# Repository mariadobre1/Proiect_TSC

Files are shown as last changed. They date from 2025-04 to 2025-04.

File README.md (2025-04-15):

# OpenBook

## Prezentare generala

Proiectul a fost realizat în cadrul disciplinei Testarea Sistemelor de Calcul și are ca scop crearea unui model 3D detaliat pentru o tabletă E-Book Reader. Am realizat proiectarea atât la nivel de circuit, cât și la nivel de design al produsului, utilizând programul Fusion360 de la Autodesk.

## Block Diagram
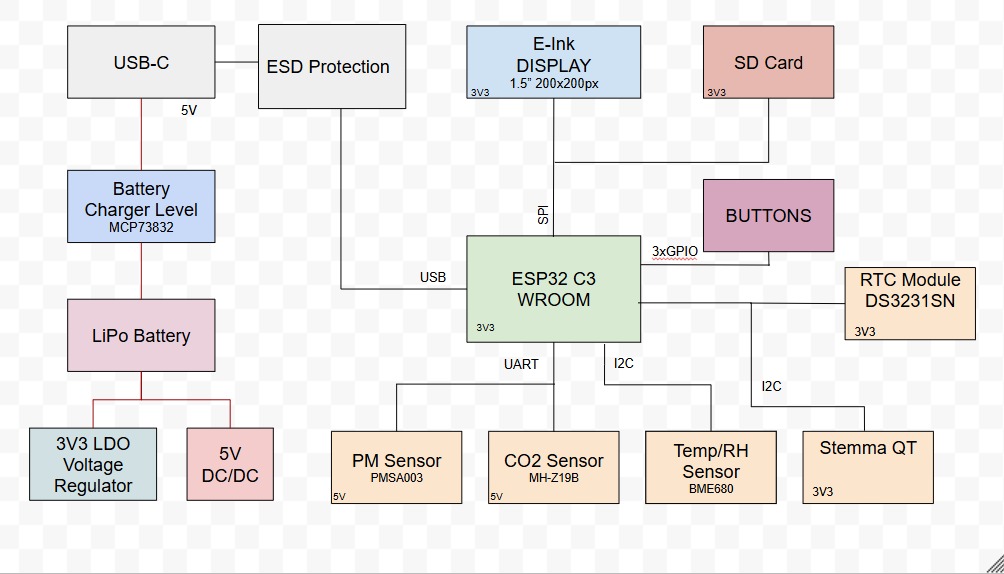
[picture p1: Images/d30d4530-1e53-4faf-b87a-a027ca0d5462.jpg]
DiagramaBloc


## Bill of Materials
| Componenta | Link | Datasheet |
|---|---|---|
| BUTTON | [Model](https://industry.panasonic.com/global/en/products/control/switch/light-touch/number/evqpuj02k) | [Datasheet](https://www.lcsc.com/datasheet/lcsc_datasheet_2201121800_PANASONIC-EVQPUJ02K_C2936858.pdf) |
| CAPACITOR | [Model](https://componentsearchengine.com/part-view/R0402%201%25%20100%20K%20(RC0402FR-07100KL)/YAGEO) | [Datasheet](//efaidnbmnnnibpcajpcglclefindmkaj/https://www.resistor.com/assets/pdf/0402tstd.pdf) |
| CPH3225A | [Model](https://www.snapeda.com/parts/CPH3225A/Seiko+Instruments/view-part/?ref=eda) | [Datasheet](https://octopart.com/datasheet/cph3225a-seiko-25340571) |
| EVQPUJ02K | [Model](https://industry.panasonic.com/global/en/products/control/switch/light-touch/number/evqpuj02k) | [Datasheet](https://www.lcsc.com/datasheet/lcsc_datasheet_2201121800_PANASONIC-EVQPUJ02K_C2936858.pdf) |
| KP-1608SURCK | [Model](https://www.snapeda.com/parts/KP-1608SURCK/Kingbright/view-part/?ref=search&t=LED%200603) | [Datasheet](//efaidnbmnnnibpcajpcglclefindmkaj/https://media.elv.com/file/107153_led_surck1608_data.pdf) |
| USBLC6-2SC6Y | [Model](https://www.snapeda.com/parts/USBLC6-2SC6Y/STMicroelectronics/view-part/?ref=eda) | [Datasheet](https://www.digikey.com/en/htmldatasheets/production/1375342/0/0/1/usblc6-2sc6y) |
| SD0805S020S1R0 | [Model](https://ro.mouser.com/ProductDetail/KYOCERA-AVX/SD0805S020S1R0?qs=jCA%252BPfw4LHbpkAoSnwrdjw%3D%3D) | [Datasheet](https://www.alldatasheet.com/view.jsp?Searchword=SD0805S&sField=2) |
| PGB1010603MR | [Model](https://www.snapeda.com/parts/PGB1010603MR/Littelfuse/view-part/?ref=eda) | [Datasheet](https://www.alldatasheet.com/view.jsp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) |
| BD5229G-TR  | [Model](https://componentsearchengine.com/part-view/BD5229G-TR/ROHM%20Semiconductor) | [Datasheet](https://www.lcsc.com/datasheet/lcsc_datasheet_2201131330_ROHM-Semicon-BD5229G-TR_C962636.pdf) |
| XC6220A331MR-G | [Model](https://componentsearchengine.com/part-view/XC6220A331MR-G/Torex) | [Datasheet](https://www.alldatasheet.com/view.jsp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) |
| XC6220A331MR-G | [Model](https://componentsearchengine.com/part-view/XC6220A331MR-G/Torex) | [Datasheet](https://www.alldatasheet.com/view.jsp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) |
| USB4110-GF-A  | [Model](https://componentsearchengine.com/part-view/USB4110-GF-A/GCT%20(GLOBAL%20CONNECTOR%20TECHNOLOGY)) | [Datasheet](//efaidnbmnnnibpcajpcglclefindmkaj/https://gct.co/files/drawings/usb4110.pdf) |
| Adafruit | [Model](https://eu.mouser.com/ProductDetail/Adafruit/4208?qs=PzGy0jfpSMtbScLbr0L5dw%3D%3D) | [Datasheet](https://www.arrow.com/en/manufacturers/adafruit-industries/datasheets) |
| Bobina | [Model](https://store.comet.srl.ro/Catalogue/Product/43497/) | [Datasheet](https://www.scribd.com/document/814581278/Datasheet-Bobina) |
| PFMF | [Model](https://www.mouser.co.uk/ProductDetail/EPCOS-TDK/B72520T0350K062?qs=dEfas%2FXlABIszF52uu7vrg%3D%3D) | [Datasheet](https://ro.mouser.com/c/ds/circuit-protection/thermistors/resettable-fuses-pptc/?m=Schurter&series=PFMF) |
| DMG2305UX-7 | [Model](https://componentsearchengine.com/part-view/DMG2305UX-7/Diodes%20Incorporated) | [Datasheet](//efaidnbmnnnibpcajpcglclefindmkaj/https://www.mouser.com/datasheet/2/115/DMG2305UX-266242.pdf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) |
| Si1308EDL-T1-GE3 | [Model](https://componentsearchengine.com/part-view/SI1308EDL-T1-GE3/Vishay) | [Datasheet](https://www.alldatasheet.com/view.jsp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) |
| R0402 | [Model](https://componentsearchengine.com/part-view/R0402%201%25%20100%20K%20(RC0402FR-07100KL)/YAGEO) | [Datasheet](//efaidnbmnnnibpcajpcglclefindmkaj/https://www.resistor.com/assets/pdf/0402tstd.pdf) |
| BME680 | [Model](https://www.snapeda.com/parts/BME680/Bosch/view-part/?welcome=home) | [Datasheet](//efaidnbmnnnibpcajpcglclefindmkaj/https://www.bosch-sensortec.com/media/boschsensortec/downloads/datasheets/bst-bme680-ds001.pdf) |
| SMD Solder | [Model](https://grabcad.com/library/solder-jumpers-1) | [Datasheet]() |
| W25Q512JVEIQ | [Model](https://www.snapeda.com/parts/ESP32-C6-WROOM-1-N8/Espressif+Systems/view-part/?ref=eda) | [Datasheet](//efaidnbmnnnibpcajpcglclefindmkaj/https://www.mouser.com/datasheet/2/949/W25Q512JV_SPI_RevB_06252019_KMS-2487502.pdf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) |
| ESP32-C6-WROOM-1-N8 | [Model](https://www.snapeda.com/parts/ESP32-C6-WROOM-1-N8/Espressif+Systems/view-part/?ref=eda) | [Datasheet](//efaidnbmnnnibpcajpcglclefindmkaj/https://www.mouser.com/catalog/specsheets/Espressif_ESP32_C6_WROOM_1%20_Datasheet_V0.1_PRELIMINARY_en.pdf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) |
| DS3231SN# | [Model](https://www.snapeda.com/parts/DS3231SN%23/Analog+Devices/view-part/?ref=eda) | [Datasheet](https://www.alldatasheet.com/view.jsp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) |
| MAX17048G+T10 | [Model](https://www.snapeda.com/parts/MAX17048G+T10/Analog+Devices/view-part/?ref=eda) | [Datasheet](https://www.alldatasheet.com/view.jsp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) |
| MCP73831T-5ACI/OT | [Model](https://www.mouser.co.uk/ProductDetail/Microchip-Technology/MCP73831T-5ACI-OT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) | [Datasheet](//efaidnbmnnnibpcajpcglclefindmkaj/https://ww1.microchip.com/downloads/en/DeviceDoc/MCP73831-Family-Data-Sheet-DS20001984H.pdf) |
## Functionalitate hardware
Componentele principale ale circuitului sunt:

 USB C Connector + ESD Protection
  
 > Se conectează prin portul USB si este folositor pentru alimentarea E-book-ului.
 
 SD Card
 
 > Cardul Secure Digital este utilizat pentru stocarea cărților în format electronic. Funcționează la 3.3V și se conectează la microcontroller prin intermediul unei interfețe SPI.
 
 E-Paper Display, impreuna cu modulele aferente - E-Paper Drive Circuit, E-Paper Display Header, EPD Power
  
> Header-ul EPD se conectează la microcontroller prin SPI și face legătura între celelalte componente. Modulul EPD Power furnizează mai multe tensiuni, iar Circuitul de Alimentare E-Paper generează semnalele necesare pentru funcționarea display-ului E-Paper.
 
 Senzorul de Mediu BME688
  
 > Acesta este un senzor capabil să măsoare temperatura, umiditatea, presiunea atmosferică și calitatea aerului. Funcționează la 3.3V și se conectează la microcontroller prin interfața I2C.

 Modul RTC DS3231SN
  
 > Acest modul Real-Time Clock are rolul de a păstra data și ora corectă chiar și atunci când microcontroller-ul este oprit. Funcționează pe baterie și include un cristal de 32KHz. Se conectează la ESP32-C6 prin I2C, utilizând pinii SCL și SDA.

 Flash NOR Extern 64MB
  
> Aceasta extinde memoria microcontroller-ului, permițând stocarea unor date suplimentare și chiar stocare temporară. Folosește interfața SPI.

 Regulator de Tensiune LDO
  
> este un stabilizator de tensiune liniar, care asigura tensiunea de iesire constanta la valoarea de 3.3V pentru microcontroller; are un consum energetic foarte mic, ceea ce il face ideal pentru dispozitive alimentate pe baza de baterie, precum cel de fata

 Supraveghetor de Tensiune
  
> folosit pentru monitorizeaza nivelului tensiunii, si pentru a asigura ca sistemul nu poate porni atunci cand avem o tensiune instabila sau mult prea mica

 Qwiic/Stemma QT
  
> Acesta simplifică conectarea senzorilor și perifericelor la microcontroller, permițând conectarea mai multor dispozitive într-un lanț, fără a fi necesare cabluri separate pentru fiecare semnal. Funcționează pe baza protocolului I2C

## Microcontroller - ESP32-C6
Întregul circuit a fost conceput în jurul microcontrollerului ESP32-C6-WROOM, un modul preasamblat.
-- Placa ESP32-WROOM-32 dispune de multiple interfețe pentru conectarea la diferite componente și senzori, cum ar fi pini de I/O, SPI, I2C și UART. Aceste interfețe facilitează integrarea componentelor externe și lărgesc gama de aplicații posibile. De asemenea, placa suportă WiFi 6 pe 2.4 GHz, are Bluetooth 5 integrat și include o antenă dedicată.

 - **Restul pinilor**
 - **FLASH_CS** este un pin Chip Select pentru selectarea chipului flash extern (pentru comunicarea SPI cu External NOR Flash)
 - **IO/BOOT** folosit pentru a intra in boot mode – legatura cu butonul de _boot_
 - **RTC_PWM** pentru semnale Pulse Width Modulation trimise catre Real Time Clock
 - **RTC_RST** pentru resetarea ceasului
- **INT_RTC** destinat semnalelor de intrerupere de la modulul RTC, de exemplu in cazul iesirii din moduri de functionare (sleep), pentru executarea unor sarcini periodice, cum ar fi un refresh al display-ului etc.

 ESP32-C6 se leaga de cele mai importante module ale circuitului prin intermediul pinilor sai:
 - **Alimentare si reset**
 **3V3** aigura alimentrea modulului, **GND** legatura la masa, **EN** trebuie sa fie pe pozitia _HIGH_ pentru ca modulul sa functioneze (EN va fi controlat de catre butonul RESET)
 - **USB C Connector**
 deoarece ESP32-C6 are USB nativ, conexiunea se realizeaza direct prin liniile de date **USB_D+** si **USB_D-**, la pinii **GPIO13** si **GPIO14** ai modulului; nu mai este deci nevoie de un convertor serial extern
 - **SD Card**
 pentru a comunica cu dispozitive rapide precum SD Card se foloseste interfata SPI(Serial Peripheral Interface), folosind pinii **GPIO27(MISO)** - pentru transfer de la card la ESP, **GPIO7(MOSI)** - pentru transfer invers, **GPIO6(SCK)** -semnalul de ceas care asigura sincronizarea, respectiv **GPIO4(SS_SD)** - chip select
 - **E-Paper Display**
 pentru conexiunea si controlul ecranului dispozitivului se folosesc pinii **GPIO11(EPD_CS)** - Chip Select pentru display-ul EPD, **GPIO5(EPD_DC)** - pentru controlul display-ului, **GPIO21(EPD_RST)** - pentru resetarea display-ului, respectiv **GPIO26(EPD_BUSY)**
 - **Environmental Sensor BME688**
 avand in vedere ca se face comunicatia cu senzorul prin intermediul protocolului I2C, pentru stabilirea legaturii se vor folosi pinii **GPIO19(SDA)**, **GPIO20(SCL)** si **GPIO17(I2C_PW)** de pe microcontroller
 - **UART(Serial Communication)**
 ESP32-C6 are si interfete seriale, utile pentru debugging sau conexiuni cu alte dispozitive; pinii aferenti comunicarii UART sunt **TXD0** -pentru transmisia datelor respectiv **RXD0** - pentru receptie de date

## Erori
Urmatoarele erori au fost observate la finalizarea PCB-ului:
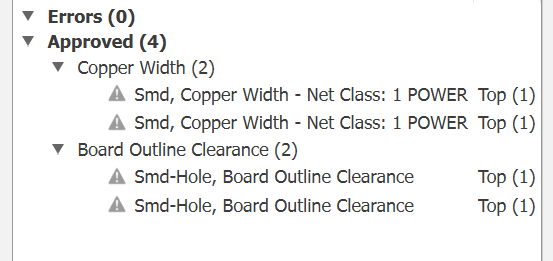
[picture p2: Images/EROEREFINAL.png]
errors


Nu sunt erori care afecteaza functionalitatea(se refera la dimensiunea portului USB sau alte mici diferente)

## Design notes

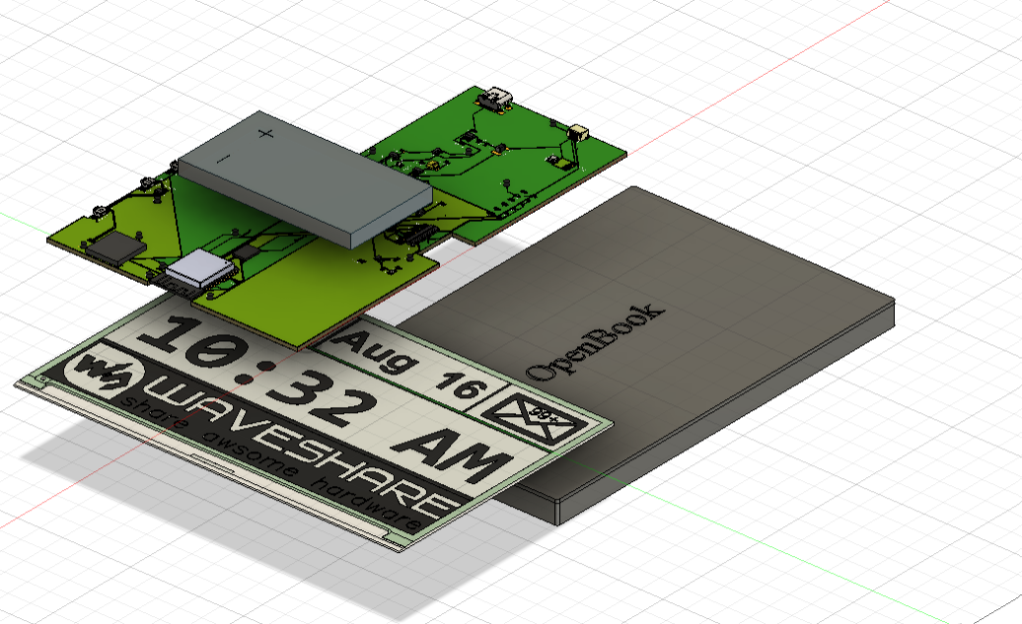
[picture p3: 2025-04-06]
Images/Screenshot 2025-04-06 200350.png

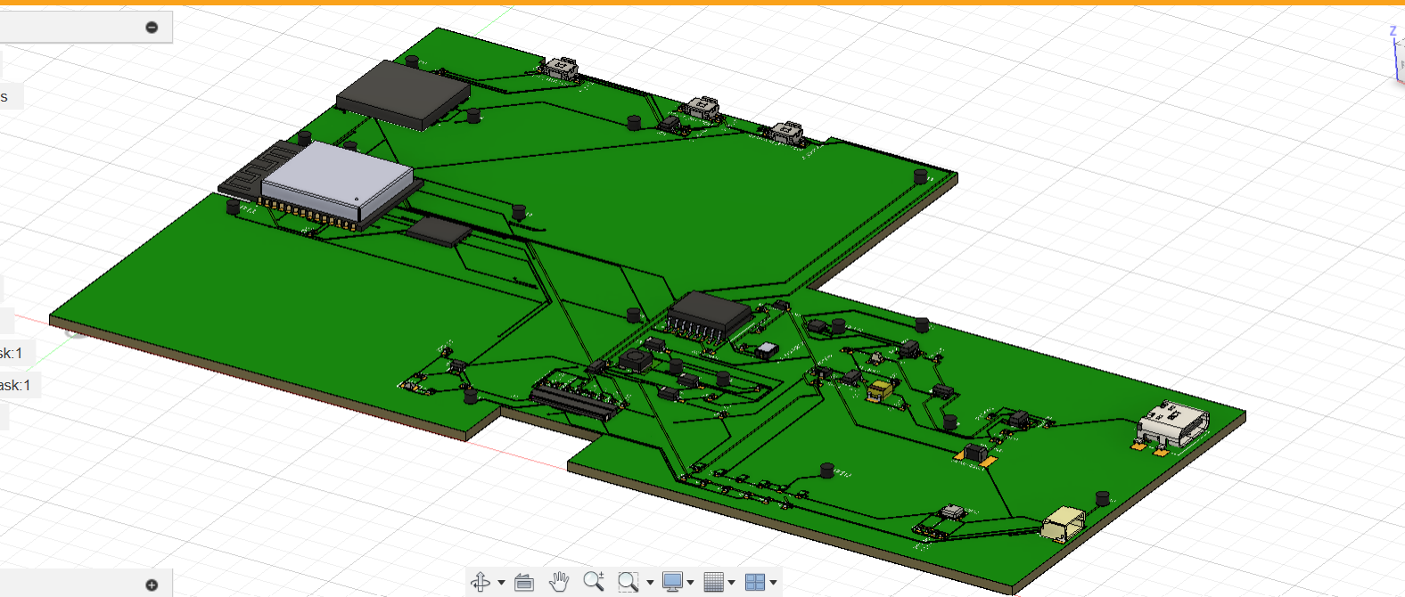
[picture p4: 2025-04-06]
Images/Screenshot 2025-04-06 200451.png

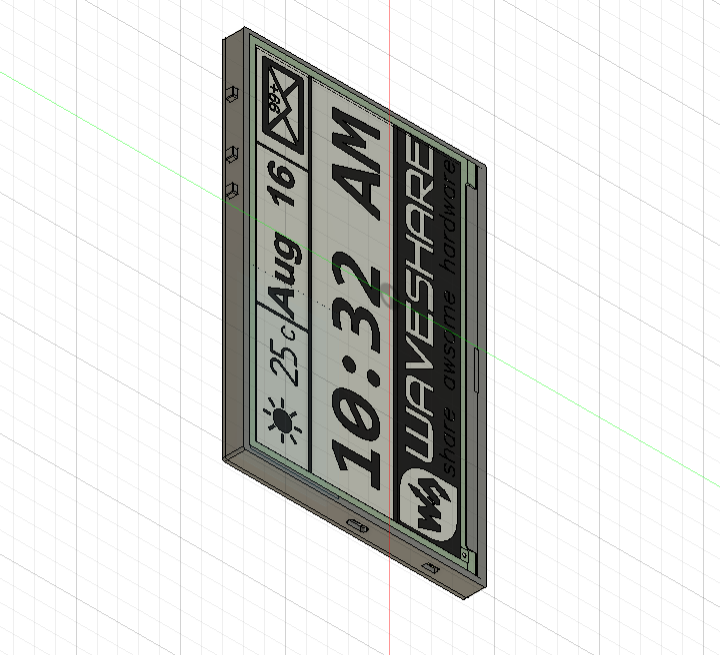
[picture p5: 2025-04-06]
Images/Screenshot 2025-04-06 200221.png

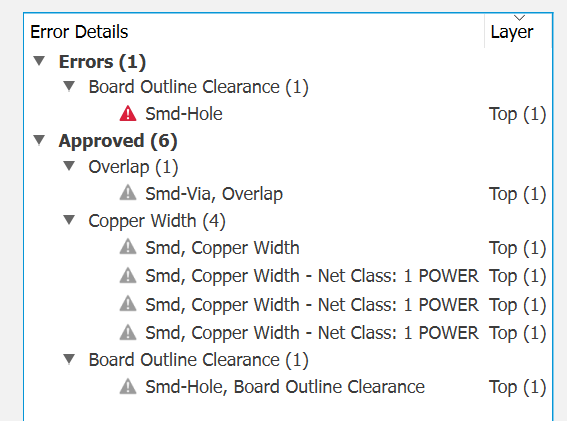
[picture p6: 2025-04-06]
Images/erori.png

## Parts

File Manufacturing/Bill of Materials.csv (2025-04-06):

Qty | Value | Device | Package | Parts | Description | ARROW_PART_NUMBER | ARROW_PRICE-STOCK | AVAILABILITY | CENTROID_NOT_SPECIFIED | CHECK_PRICES | COPYRIGHT | DATASHEET | DESCRIPTION | DIGIKEY_DESCRIPTION | DIGIKEY_PART_NUMBER | HEIGHT | LEAD_FREE | MANUFACTURER_NAME | MANUFACTURER_PART_NUMBER | MF | MFR_NAME | MOUSER_PART_NUMBER | MOUSER_PRICE-STOCK | MOUSER_TESTING_PART_NUMBER | MOUSER_TESTING_PRICE-STOCK | MP | MPN | PACKAGE | POPULARITY | PREFIX | PRICE | PROD_ID | PURCHASE-URL | ROHS | SNAPEDA_LINK | SPICEMODEL | SPICEPREFIX | TEMPERATURE_RANGE_HIGH | TEMPERATURE_RANGE_LOW | THERMALLOSS | TP_SIGNAL_NAME | VALUE | LSCS Part Number
1 |  | ADAFRUIT_LEDCHIP-LED0603 | ADAFRUIT_CHIP-LED0603 | CHG_LED | LED |  |  |  |  |  |  |  |  |  |  |  |  |  |  |  |  |  |  |  |  |  |  |  |  |  |  |  |  |  |  |  |  |  |  |  |  |  | https://www.snapeda.com/parts/KP-1608SURCK/Kingbright/view-part/?ref=search&t=LED%200603
1 |  | SJ | SJ | SJ1 | SMD solder JUMPER |  |  |  |  |  |  |  |  |  |  |  |  |  |  |  |  |  |  |  |  |  |  |  | 3 |  |  |  |  |  |  |  |  |  |  |  |  |  | https://grabcad.com/library/solder-jumpers-1
1 | 0.1uF/50V | ESP32_WROVER_EAGLE-LTSPICE_CC0402 | ESP32_WROVER_EAGLE-LTSPICE_C0402 | EPD_C5 | CAPACITOR, European symbol |  |  |  |  |  |  |  |  |  |  |  |  |  |  |  |  |  |  |  |  |  |  |  |  |  |  |  |  |  |  | NONE | C |  |  |  |  |  | https://componentsearchengine.com/part-view/C0402C682K4REC7411/KEMET
1 | 0.47 | ESP32_WROVER_EAGLE-LTSPICE_RR0402 | ESP32_WROVER_EAGLE-LTSPICE_R0402 | R3 | RESISTOR, European symbol |  |  |  |  |  |  |  |  |  |  |  |  |  |  |  |  |  |  |  |  |  |  |  |  |  |  |  |  |  |  | NONE | R |  |  |  |  |  | https://componentsearchengine.com/part-view/R0402%201%25%20100%20K%20(RC0402FR-07100KL)/YAGEO
1 | 100K | ESP32_WROVER_EAGLE-LTSPICE_RR0402 | ESP32_WROVER_EAGLE-LTSPICE_R0402 | R1_PWRUSB | RESISTOR, European symbol |  |  |  |  |  |  |  |  |  |  |  |  |  |  |  |  |  |  |  |  |  |  |  |  |  |  |  |  |  |  | NONE | R |  |  |  |  |  | https://componentsearchengine.com/part-view/R0402%201%25%20100%20K%20(RC0402FR-07100KL)/YAGEO
8 | 100nF | ESP32_WROVER_EAGLE-LTSPICE_CC0402 | ESP32_WROVER_EAGLE-LTSPICE_C0402 | C1, C2, C4_USB, C6, C8, C9, C10, C_DELAY | CAPACITOR, European symbol |  |  |  |  |  |  |  |  |  |  |  |  |  |  |  |  |  |  |  |  |  |  |  |  |  |  |  |  |  |  | NONE | C |  |  |  |  |  | https://componentsearchengine.com/part-view/C0402C682K4REC7411/KEMET
1 | 100uF TANT | RCL_CPOL-EUCT3528 | RCL_CT3528 | C3 | POLARIZED CAPACITOR, European symbol |  |  |  |  |  |  |  |  |  |  |  |  |  |  |  |  |  |  |  |  |  |  |  | 0 |  |  |  |  |  |  |  | C |  |  |  |  |  | https://componentsearchengine.com/part-view/CPH3225A/Seiko%20Semiconductors
16 | 10K | ESP32_WROVER_EAGLE-LTSPICE_RR0402 | ESP32_WROVER_EAGLE-LTSPICE_R0402 | R1, R1_PINH, R1_PINH1, R2-PINH, R2-PINH1, R4, R5, R6, R7, R8, R9, R10, R_BOOT, R_CHANGE, R_CL1, R_RESET | RESISTOR, European symbol |  |  |  |  |  |  |  |  |  |  |  |  |  |  |  |  |  |  |  |  |  |  |  |  |  |  |  |  |  |  | NONE | R |  |  |  |  |  | https://componentsearchengine.com/part-view/R0402%201%25%20100%20K%20(RC0402FR-07100KL)/YAGEO
1 | 10uF | ESP32_WROVER_EAGLE-LTSPICE_CC0402 | ESP32_WROVER_EAGLE-LTSPICE_C0402 | C7 | CAPACITOR, European symbol |  |  |  |  |  |  |  |  |  |  |  |  |  |  |  |  |  |  |  |  |  |  |  |  |  |  |  |  |  |  | NONE | C |  |  |  |  |  | https://componentsearchengine.com/part-view/C0402C682K4REC7411/KEMET
1 | 112A-TAAR-R03_ATTEND | 112A-TAAR-R03_ATTEND | 112ATAARR03ATTEND | J4 | Micro SD Card Socket, Push-Push Type, Top Mount, SMT, H=1.83mm, 10u |  |  |  |  |  |  |  | Micro SD Card Socket | Push-Push Type | Top Mount | SMT | H=1.83mm | 10u |  |  | 1.9mm |  | ATTEND | 112A-TAAR-R03 ATTEND |  |  |  |  |  |  |  |  |  |  |  |  |  |  |  |  |  |  | https://componentsearchengine.com/part-view/112A-TAAR-R03%20ATTEND/ATTEND
1 | 15 | ESP32_WROVER_EAGLE-LTSPICE_RR0402 | ESP32_WROVER_EAGLE-LTSPICE_R0402 | R_CAPACITOR | RESISTOR, European symbol |  |  |  |  |  |  |  |  |  |  |  |  |  |  |  |  |  |  |  |  |  |  |  |  |  |  |  |  |  |  | NONE | R |  |  |  |  |  | https://componentsearchengine.com/part-view/R0402%201%25%20100%20K%20(RC0402FR-07100KL)/YAGEO
1 | 1uF | ESP32_WROVER_EAGLE-LTSPICE_CC0402 | ESP32_WROVER_EAGLE-LTSPICE_C0402 | C5 | CAPACITOR, European symbol |  |  |  |  |  |  |  |  |  |  |  |  |  |  |  |  |  |  |  |  |  |  |  |  |  |  |  |  |  |  | NONE | C |  |  |  |  |  | https://componentsearchengine.com/part-view/C0402C682K4REC7411/KEMET
9 | 1uF/50V | ESP32_WROVER_EAGLE-LTSPICE_CC0402 | ESP32_WROVER_EAGLE-LTSPICE_C0402 | EPD_C1, EPD_C2, EPD_C6, EPD_C7, EPD_C8, EPD_C9, EPD_C10, EPD_C11, EPD_C12 | CAPACITOR, European symbol |  |  |  |  |  |  |  |  |  |  |  |  |  |  |  |  |  |  |  |  |  |  |  |  |  |  |  |  |  |  | NONE | C |  |  |  |  |  | https://componentsearchengine.com/part-view/C0402C682K4REC7411/KEMET
1 | 2.2 | ESP32_WROVER_EAGLE-LTSPICE_RR0402 | ESP32_WROVER_EAGLE-LTSPICE_R0402 | R2 | RESISTOR, European symbol |  |  |  |  |  |  |  |  |  |  |  |  |  |  |  |  |  |  |  |  |  |  |  |  |  |  |  |  |  |  | NONE | R |  |  |  |  |  | https://componentsearchengine.com/part-view/R0402%201%25%20100%20K%20(RC0402FR-07100KL)/YAGEO
1 | 200 | ESP32_WROVER_EAGLE-LTSPICE_RR0402 | ESP32_WROVER_EAGLE-LTSPICE_R0402 | R1_BAT | RESISTOR, European symbol |  |  |  |  |  |  |  |  |  |  |  |  |  |  |  |  |  |  |  |  |  |  |  |  |  |  |  |  |  |  | NONE | R |  |  |  |  |  | https://componentsearchengine.com/part-view/R0402%201%25%20100%20K%20(RC0402FR-07100KL)/YAGEO
1 | 20V/4.2A/52mO/1.4W | ESP32_WROVER_SPARKFUN-DISCRETESEMI_MOSFET_PCH-DMG2305UX-7 | ESP32_WROVER_SPARKFUN-DISCRETESEMI_SOT23-3 | Q1 | P-channel MOSFETs |  |  |  |  |  |  |  |  |  |  |  |  |  |  |  |  |  |  |  |  |  |  |  |  |  |  | TRAN-14388 |  |  |  |  |  |  |  |  |  | 20V/4.2A/52mO/1.4W | https://componentsearchengine.com/part-view/DMG2305UX-7/Diodes%20Incorporated
1 | 20V/4.2A/52mO/1.4W | ESP32_WROVER_SPARKFUN-DISCRETESEMI_MOSFET_PCH-DMG2305UX-7 | ESP32_WROVER_SPARKFUN-DISCRETESEMI_SOT23-3 | Q2 | P-channel MOSFETs |  |  |  |  |  |  |  |  |  |  |  |  |  |  |  |  |  |  |  |  |  |  |  |  |  |  | TRAN-14388 |  |  |  |  |  |  |  | 2305 UX |  | 20V/4.2A/52mO/1.4W | https://componentsearchengine.com/part-view/DMG2305UX-7/Diodes%20Incorporated
1 | 2K | ESP32_WROVER_EAGLE-LTSPICE_RR0402 | ESP32_WROVER_EAGLE-LTSPICE_R0402 | R2_BAT | RESISTOR, European symbol |  |  |  |  |  |  |  |  |  |  |  |  |  |  |  |  |  |  |  |  |  |  |  |  |  |  |  |  |  |  | NONE | R |  |  |  |  |  | https://componentsearchengine.com/part-view/R0402%201%25%20100%20K%20(RC0402FR-07100KL)/YAGEO
5 | 4.7uF | ESP32_WROVER_EAGLE-LTSPICE_CC0402 | ESP32_WROVER_EAGLE-LTSPICE_C0402 | C1_BAT, C1_BAT1, C1_BAT2, C2_BAT, C5_USB | CAPACITOR, European symbol |  |  |  |  |  |  |  |  |  |  |  |  |  |  |  |  |  |  |  |  |  |  |  |  |  |  |  |  |  |  | NONE | C |  |  |  |  |  | https://componentsearchengine.com/part-view/C0402C682K4REC7411/KEMET
1 | 4.7uF/25V | ESP32_WROVER_EAGLE-LTSPICE_CC0402 | ESP32_WROVER_EAGLE-LTSPICE_C0402 | C4 | CAPACITOR, European symbol |  |  |  |  |  |  |  |  |  |  |  |  |  |  |  |  |  |  |  |  |  |  |  |  |  |  |  |  |  |  | NONE | C |  |  |  |  |  | https://componentsearchengine.com/part-view/C0402C682K4REC7411/KEMET
2 | 5k1 | ESP32_WROVER_EAGLE-LTSPICE_RR0402 | ESP32_WROVER_EAGLE-LTSPICE_R0402 | R2-USB, R2-USB1 | RESISTOR, European symbol |  |  |  |  |  |  |  |  |  |  |  |  |  |  |  |  |  |  |  |  |  |  |  |  |  |  |  |  |  |  | NONE | R |  |  |  |  |  | https://componentsearchengine.com/part-view/R0402%201%25%20100%20K%20(RC0402FR-07100KL)/YAGEO
1 | 68uH | 744043680IND_4828-WE-TPC_WRE | IND_4828-WE-TPC_WRE | L1 |  |  |  |  |  |  | Copyright (C) 2024 Ultra Librarian. All rights reserved. |  |  |  |  |  |  |  | 744043680 |  | Wurth Electronics |  |  |  |  |  |  |  |  |  |  |  |  |  |  |  |  |  |  |  |  |  | https://ro.mouser.com/ProductDetail/Wurth-Elektronik/744043680?qs=PGXP4M47uW6VkZq%252BkzjrHA%3D%3D
1 | BD5229G-TR | BD5229G-TR | SOT95P280X125-5N | IC1 | Voltage Detector with Adjustable Delay Time: CMOS processes are utilized to develop high precision, low current consumption CMOS reset ICs that allow arbitrary setting of the delay time. The extensive lineup includes both Nch Open Drain and CMOS output types in a wide range of detection voltages (from 2.3V to 6.0V, in 0.1V steps), enabling selection of the ideal solution based on customer requirements. In addition, the entire series is of course both lead-free and RoHS-compliant. |  |  |  |  |  |  |  | Voltage Detector with Adjustable Delay Time: CMOS processes are utilized to develop high precision | low current consumption CMOS reset ICs that allow arbitrary setting of the delay time. The extensive lineup includes both Nch Open Drain and CMOS output types in a wide range of detection voltages (from 2.3V to 6.0V | in 0.1V steps) | enabling selection of the ideal solution based on customer requirements. In addition | the entire series is of course both lead-free and RoHS-compliant. |  |  | 1.25mm |  | ROHM Semiconductor | BD5229G-TR |  |  | 755-BD5229G-TR | https://www.mouser.co.uk/ProductDetail/ROHM-Semiconductor/BD5229G-TR?qs=4kLU8WoGk0vvnhrrYwdszw%3D%3D |  |  |  |  |  |  |  |  |  |  |  |  |  |  |  | https://componentsearchengine.com/part-view/BD5229G-TR/ROHM%20Semiconductor
1 | BME688 | ESP32_WROVER_BME680_BME680 | ESP32_WROVER_BME680_PSON80P300X300X100-8N | SENSOR2 | Integrated Environmental Unit |  |  | Unavailable |  |  |  |  | Integrated Environmental Unit |  |  |  |  |  |  | Bosch Sensortec |  |  |  |  |  | BME680 |  | LGA-8 Bosch Tools |  |  | None |  |  |  |  |  |  |  |  |  |  |  | https://www.snapeda.com/parts/BME680/Bosch/view-part/?welcome=home
3 | BUTTON_CUSYOMV1 | BUTTON_CUSYOMV1 | MYBUTTON | BOOT_BUTTON, CHANGE_BUTTON, RESET_BUTTON |  |  |  |  |  |  |  |  |  |  |  |  |  |  |  |  |  |  |  |  |  |  |  |  |  |  |  |  |  |  |  |  |  |  |  |  |  |  | https://industry.panasonic.com/global/en/products/control/switch/light-touch/number/evqpuj02k
1 | CPH3225A | CPH3225A | CAPCP3225X100N | C10_SUPERCAP | Cap 0.011F 3.3V 1210 Flat Check availability |  |  | Not in stock |  | https://www.snapeda.com/parts/CPH3225A/Seiko+Instruments/view-part/?ref=eda |  |  | 11 mF (EDLC) Supercapacitor 3.3 V 1210 (3225 Metric) - - |  |  |  |  |  |  | Seiko Instruments |  |  |  |  |  | CPH3225A |  | 1210 Seiko |  |  | None |  | https://www.snapeda.com/api/url_track_click_mouser/?unipart_id=562593&manufacturer=Seiko Instruments&part_name=CPH3225A&search_term=None |  | https://www.snapeda.com/parts/CPH3225A/Seiko+Instruments/view-part/?ref=snap |  |  |  |  |  |  |  | https://www.snapeda.com/parts/CPH3225A/Seiko+Instruments/view-part/?ref=eda
1 | DS3231SN# | DS3231SN# | SOIC127P1032X265-16N | U3 | Real Time Clock Serial 16-Pin SOIC W T/R Check availability |  |  | In Stock |  | https://www.snapeda.com/parts/DS3231SN%23/Analog+Devices/view-part/?ref=eda |  |  | Extremely Accurate I²C-Integrated RTC/TCXO/Crystal |  |  |  |  |  |  | Analog Devices |  |  |  |  |  | DS3231SN# |  | SOIC-16 Maxim |  |  | None |  | https://www.snapeda.com/api/url_track_click_mouser/?unipart_id=99048&manufacturer=Analog Devices&part_name=DS3231SN#&search_term=None |  | https://www.snapeda.com/parts/DS3231SN%23/Analog+Devices/view-part/?ref=snap |  |  |  |  |  |  |  | https://www.snapeda.com/parts/DS3231SN%23/Analog+Devices/view-part/?ref=eda
1 | ESP32-C6-WROOM-1-N8 | ESP32-C6-WROOM-1-N8 | XCVR_ESP32-C6-WROOM-1-N8 | U2 | Check availability |  |  | In Stock |  | https://www.snapeda.com/parts/ESP32-C6-WROOM-1-N8/Espressif+Systems/view-part/?ref=eda |  |  | Multiprotocol Modules ESP32-C6 module | Wi-Fi 6 in 2.4 GHz band | Bluetooth 5 | Zigbee 3.0 and Thread. ESP34-WROOM Compatible - ENGINEERING SAMPLE |  |  |  |  |  |  | Espressif Systems |  |  |  |  |  | ESP32-C6-WROOM-1-N8 |  | None |  |  | None |  |  |  | https://www.snapeda.com/parts/ESP32-C6-WROOM-1-N8/Espressif+Systems/view-part/?ref=snap |  |  |  |  | https://www.snapeda.com/parts/ESP32-C6-WROOM-1-N8/Espressif+Systems/view-part/?ref=eda
1 | ESP32C6_VARISTORCN1812 | ESP32C6_VARISTORCN1812 | ESP32C6_VARISTOR_CT/CN1812 | PFMF.050.1 | VARISTOR |  |  |  |  |  |  |  |  |  |  |  |  |  |  |  |  |  |  |  |  |  |  |  | 0 |  |  |  |  |  |  |  |  |  |  |  |  |  | https://componentsearchengine.com/part-view/PFMF.050.2/SCHURTER
2 | ESP32_WROVER_AVX---SD0805S020S1R0_AVX_SD0805S020S1R0_0_0AVX_SD0805S020S1R0_0_0 | ESP32_WROVER_AVX---SD0805S020S1R0_AVX_SD0805S020S1R0_0_0AVX_SD0805S020S1R0_0_0 | ESP32_WROVER_AVX---SD0805S020S1R0_AVX_SD0805S020S1R0_0 | D2, D7 | Schottky Barrier Rectifier Diode |  |  |  | No |  |  | http://datasheets.avx.com/schottky.pdf |  | DIODE SCHOTTKY 20V 1A 0805 | 478-7800-1-ND |  | yes |  |  | AVX |  | 581-SD0805S020S1R0 |  |  |  |  |  | 0805 (2012 metric) |  | D |  |  |  | yes |  |  |  | +125°C | -55°C |  |  |  | https://ro.mouser.com/ProductDetail/KYOCERA-AVX/SD0805S020S1R0?qs=jCA%252BPfw4LHbpkAoSnwrdjw%3D%3D
1 | ESP32_WROVER_SPARKFUN-IC-POWER_MCP73831 | ESP32_WROVER_SPARKFUN-IC-POWER_MCP73831 | ESP32_WROVER_SPARKFUN-IC-POWER_SOT23-5 | MCP73831 | MCP73831T Li-Ion, Li-Pol Controller |  |  |  |  |  |  |  |  |  |  |  |  |  |  |  |  |  |  |  |  |  |  |  |  |  |  | IC-09995 |  |  |  |  |  |  |  |  |  |  | https://ro.mouser.com/ProductDetail/Microchip-Technology/MCP73831T-5ACI-OT?qs=hH%252BOa0VZEiAcgAcEkuamXg%3D%3D
1 | FH34SRJ-24S-0.5SH_99_ | FH34SRJ-24S-0.5SH_99_ | FH34SRJ24S05SH99 | J1 | (0.50mm) Surface Mount, Right Angle |  |  |  |  |  |  |  | 24 Position FFC | FPC Connector Contacts | (0.50mm) Surface Mount | Right Angle |  |  | 1.1mm |  | Hirose | FH34SRJ-24S-0.5SH(99) |  |  | 798-FH34SRJ24S05SH99 | https://www.mouser.co.uk/ProductDetail/Hirose-Connector/FH34SRJ-24S-0.5SH99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 |  |  |  |  |  |  |  |  |  |  |  |  |  |  |  |  | https://ro.mouser.com/ProductDetail/Hirose-Connector/FH34SRJ-24S-0.5SH99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
1 | MAX17048G+T10 | MAX17048G+T10 | SON50P200X200X80-9N | U4 | Check availability |  |  | In Stock |  | https://www.snapeda.com/parts/MAX17048G+T10/Analog+Devices/view-part/?ref=eda |  |  | 3µA 1-Cell/2-Cell Fuel Gauge with ModelGauge |  |  |  |  |  |  | Analog Devices |  |  |  |  |  | MAX17048G+T10 |  | TDFN-8 Maxim |  |  | None |  | https://www.snapeda.com/api/url_track_click_mouser/?unipart_id=329239&manufacturer=Analog Devices&part_name=MAX17048G+T10&search_term=None |  | https://www.snapeda.com/parts/MAX17048G+T10/Analog+Devices/view-part/?ref=snap |  |  |  |  |  |  |  | https://www.snapeda.com/parts/MAX17048G+T10/Analog+Devices/view-part/?ref=eda
3 | MBR0530 | MBR0530 | SOD3716X135N | D3, D4, D5 | ON SEMICONDUCTOR - MBR0530 - DIODE, SCHOTTKY, 0.5A, 30V, SOD-123 |  |  | In Stock |  | https://www.snapeda.com/parts/MBR0530/Onsemi/view-part/?ref=eda |  |  | Diode Schottky 30 V 500mA Surface Mount SOD-123 |  |  |  |  |  |  | ON Semiconductor |  |  |  |  |  | MBR0530 |  | SOD-123-2 ON Semiconductor |  |  | None |  | https://www.snapeda.com/api/url_track_click_mouser/?unipart_id=179458&manufacturer=ON Semiconductor&part_name=MBR0530&search_term=None |  | https://www.snapeda.com/parts/MBR0530/Onsemi/view-part/?ref=snap |  |  |  |  |  |  |  | https://www.snapeda.com/parts/MBR0530/Onsemi/view-part/?ref=eda
6 | PGB1010603MR | PGB1010603MR | DIOC1608X36N | D6, D8, D9, D10, D11, D12 | Check availability |  |  | In Stock |  | https://www.snapeda.com/parts/PGB1010603MR/Littelfuse/view-part/?ref=eda |  |  | 150V (Typ) Clamp - Ipp Tvs Diode Surface Mount 0603 (1608 Metric) |  |  |  |  |  |  | Littelfuse Inc. |  |  |  |  |  | PGB1010603MR |  | 0603 Littelfuse Inc. |  |  | None |  | https://www.snapeda.com/api/url_track_click_mouser/?unipart_id=5659453&manufacturer=Littelfuse Inc.&part_name=PGB1010603MR&search_term=None |  | https://www.snapeda.com/parts/PGB1010603MR/Littelfuse/view-part/?ref=snap |  |  |  |  |  |  |  | https://componentsearchengine.com/part-view/PGB1010603MR/LITTELFUSE
1 | QWIIC_RIGHT_ANGLE | QWIIC_CONNECTORJS-1MM | JST04_1MM_RA | J3 | SparkFun I2C Standard Qwiic Connector |  |  |  |  |  |  |  |  |  |  |  |  |  |  |  |  |  |  |  |  |  |  |  |  |  |  | CONN-13694 |  |  |  |  |  |  |  |  |  | QWIIC_RIGHT_ANGLE | https://componentsearchengine.com/part-view/PRT-14417/SparkFun
1 | SAMACSYS_PARTS_USB4110-GF-A | SAMACSYS_PARTS_USB4110-GF-A | SAMACSYS_PARTS_USB4110GFA | J2 | CONN USB 2.0 TYPE-C R/A SMT |  |  |  |  |  |  |  | CONN USB 2.0 TYPE-C R/A SMT |  |  | 3.26mm |  | GCT (GLOBAL CONNECTOR TECHNOLOGY) | USB4110-GF-A |  |  | 640-USB4110-GF-A | https://www.mouser.co.uk/ProductDetail/GCT/USB4110-GF-A?qs=KUoIvG%2F9IlYiZvIXQjyJeA%3D%3D |  |  |  |  |  |  |  |  |  |  |  |  |  |  |  |  |  |  |  | https://ro.mouser.com/ProductDetail/GCT/USB4110-GF-A?qs=KUoIvG%2F9IlYiZvIXQjyJeA%3D%3D
1 | SI1308EDL-T1-GE3 | SI1308EDL-T1-GE3 | SOT65P210X110-3N | Q3 | MOSFET N-Ch 30V 1.5A TrenchFET SC70 Vishay Si1308EDL-T1-GE3 N-channel MOSFET Transistor, 1.5 A, 30 V, 3-Pin SC-70 |  |  | In Stock |  | https://www.snapeda.com/parts/SI1308EDL-T1-GE3/Vishay+Siliconix/view-part/?ref=eda |  |  | Si1308EDL-T1-GE3 N-channel MOSFET Transistor | 1.5 A | 30 V | 3-Pin SC-70 | Siliconix / Vishay SI1308EDL-T1-GE3 |  |  |  |  |  |  | Vishay Siliconix |  |  |  |  |  | SI1308EDL-T1-GE3 |  | SOT-323 Vishay Semiconductor |  |  | None |  | https://www.snapeda.com/api/url_track_click_mouser/?unipart_id=274603&manufacturer=Vishay Siliconix&part_name=SI1308EDL-T1-GE3&search_term=None |  | https://www.snapeda.com/parts/SI1308EDL-T1-GE3/Vishay+Siliconix/view-part/?ref=snap |  |  |  |  | https://www.snapeda.com/parts/SI1308EDL-T1-GE3/Vishay+Siliconix/view-part/?ref=eda
17 | TPTP20R | TPTP20R | TP20R | TP1, TP2, TP3, TP4, TP5, TP6, TP7, TP8, TP9, TP10, TP11, TP12, TP13, TP14, TP15, TP16, TP17 | Test pad |  |  |  |  |  |  |  |  |  |  |  |  |  |  |  |  |  |  |  |  |  |  |  | 2
1 | USBLC6-2SC6Y | USBLC6-2SC6Y | SOT95P280X145-6N | D1 | Low Cap. ESD Protection Auto SOT-23-6 STMicroelectronics USBLC6-2SC6Y, Dual Uni-Directional TVS Diode Array, 6-Pin SOT-23 |  |  | In Stock |  | https://www.snapeda.com/parts/USBLC6-2SC6Y/STMicroelectronics/view-part/?ref=eda |  |  | 17V Clamp 5A (8/20µs) Ipp Tvs Diode Surface Mount SOT-23-6 |  |  |  |  |  |  | STMicroelectronics |  |  |  |  |  | USBLC6-2SC6Y |  | SOT-23-6 STMicroelectronics |  |  | None |  |  |  | https://www.snapeda.com/parts/USBLC6-2SC6Y/STMicroelectronics/view-part/?ref=snap |  |  |  |  |  |  |  | https://www.snapeda.com/parts/USBLC6-2SC6Y/STMicroelectronics/view-part/?ref=eda
1 | W25Q512JVEIQ | W25Q512JVEIQ | SON127P600X800X80-9N | U1 | Check availability |  |  | In Stock |  | https://www.snapeda.com/parts/W25Q512JVEIQ/Winbond+Electronics/view-part/?ref=eda |  |  | FLASH - NOR Memory IC 512Mb (64M x 8) SPI - Quad I/O 133 MHz 8-WSON (8x6) |  |  |  |  |  |  | Winbond Electronics |  |  |  |  |  | W25Q512JVEIQ |  | Package |  |  | None |  |  |  | https://www.snapeda.com/parts/W25Q512JVEIQ/Winbond+Electronics/view-part/?ref=snap |  |  |  |  |  |  |  | https://www.snapeda.com/parts/W25Q512JVEIQ/Winbond+Electronics/view-part/?ref=eda
1 | XC6220A331MR-G | XC6220A331MR-G | SOT95P280X120-5N | IC4 | LDO Voltage Regulators |  |  |  |  |  |  |  | LDO Voltage Regulators |  |  | 1.2mm |  | Torex | XC6220A331MR-G |  |  | 865-XC6220A331MR-G | https://www.mouser.co.uk/ProductDetail/Torex-Semiconductor/XC6220A331MR-G?qs=AsjdqWjXhJ8ZSWznL1J0gg%3D%3D |  |  |  |  |  |  |  |  |  |  |  |  |  |  |  |  |  |  |  | https://ro.mouser.com/ProductDetail/Torex-Semiconductor/XC6220A331MR-G?qs=AsjdqWjXhJ8ZSWznL1J0gg%3D%3D
